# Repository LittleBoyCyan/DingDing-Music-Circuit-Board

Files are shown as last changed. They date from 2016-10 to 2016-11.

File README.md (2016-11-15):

# DingDing Music Circuit Board

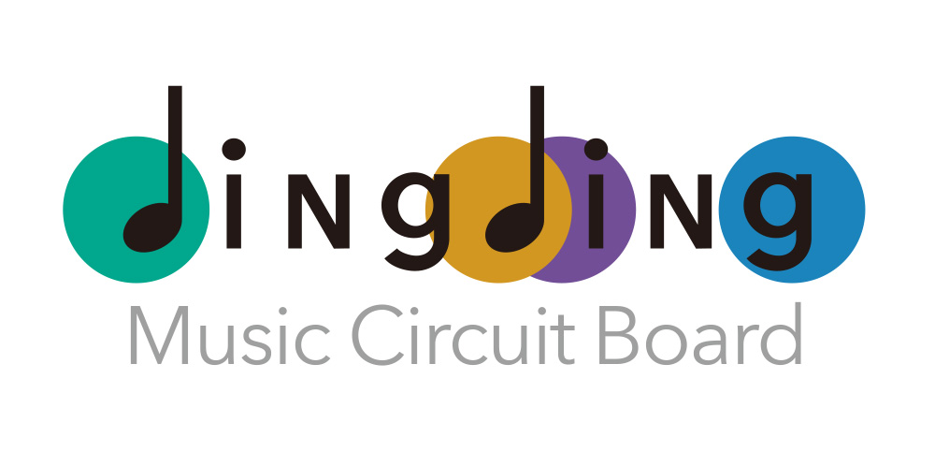
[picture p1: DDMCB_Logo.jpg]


<딩딩 뮤직 서킷 보드>는 리틀보이사이언에서 만든 아두이노 기반의 디지털 악기 보드 입니다. 

2016년 10월 서울, 세운상가에서 열린 메이커스 플랫폼 행사에서 세운상가의 마스터분들과의 협업으로 서울문화재단과 함께 제작하였습니다. 



<a href=http://bit.ly/dingdingmusiccircuitboard>악기 사용설명서 PDF 다운로드</a>

업데이트 중입니다 - - -

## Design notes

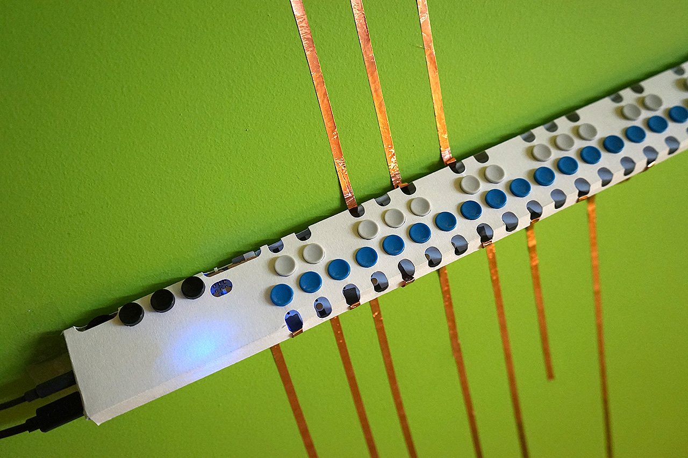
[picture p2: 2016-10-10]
DingDingMusicCircuitBoard.jpg

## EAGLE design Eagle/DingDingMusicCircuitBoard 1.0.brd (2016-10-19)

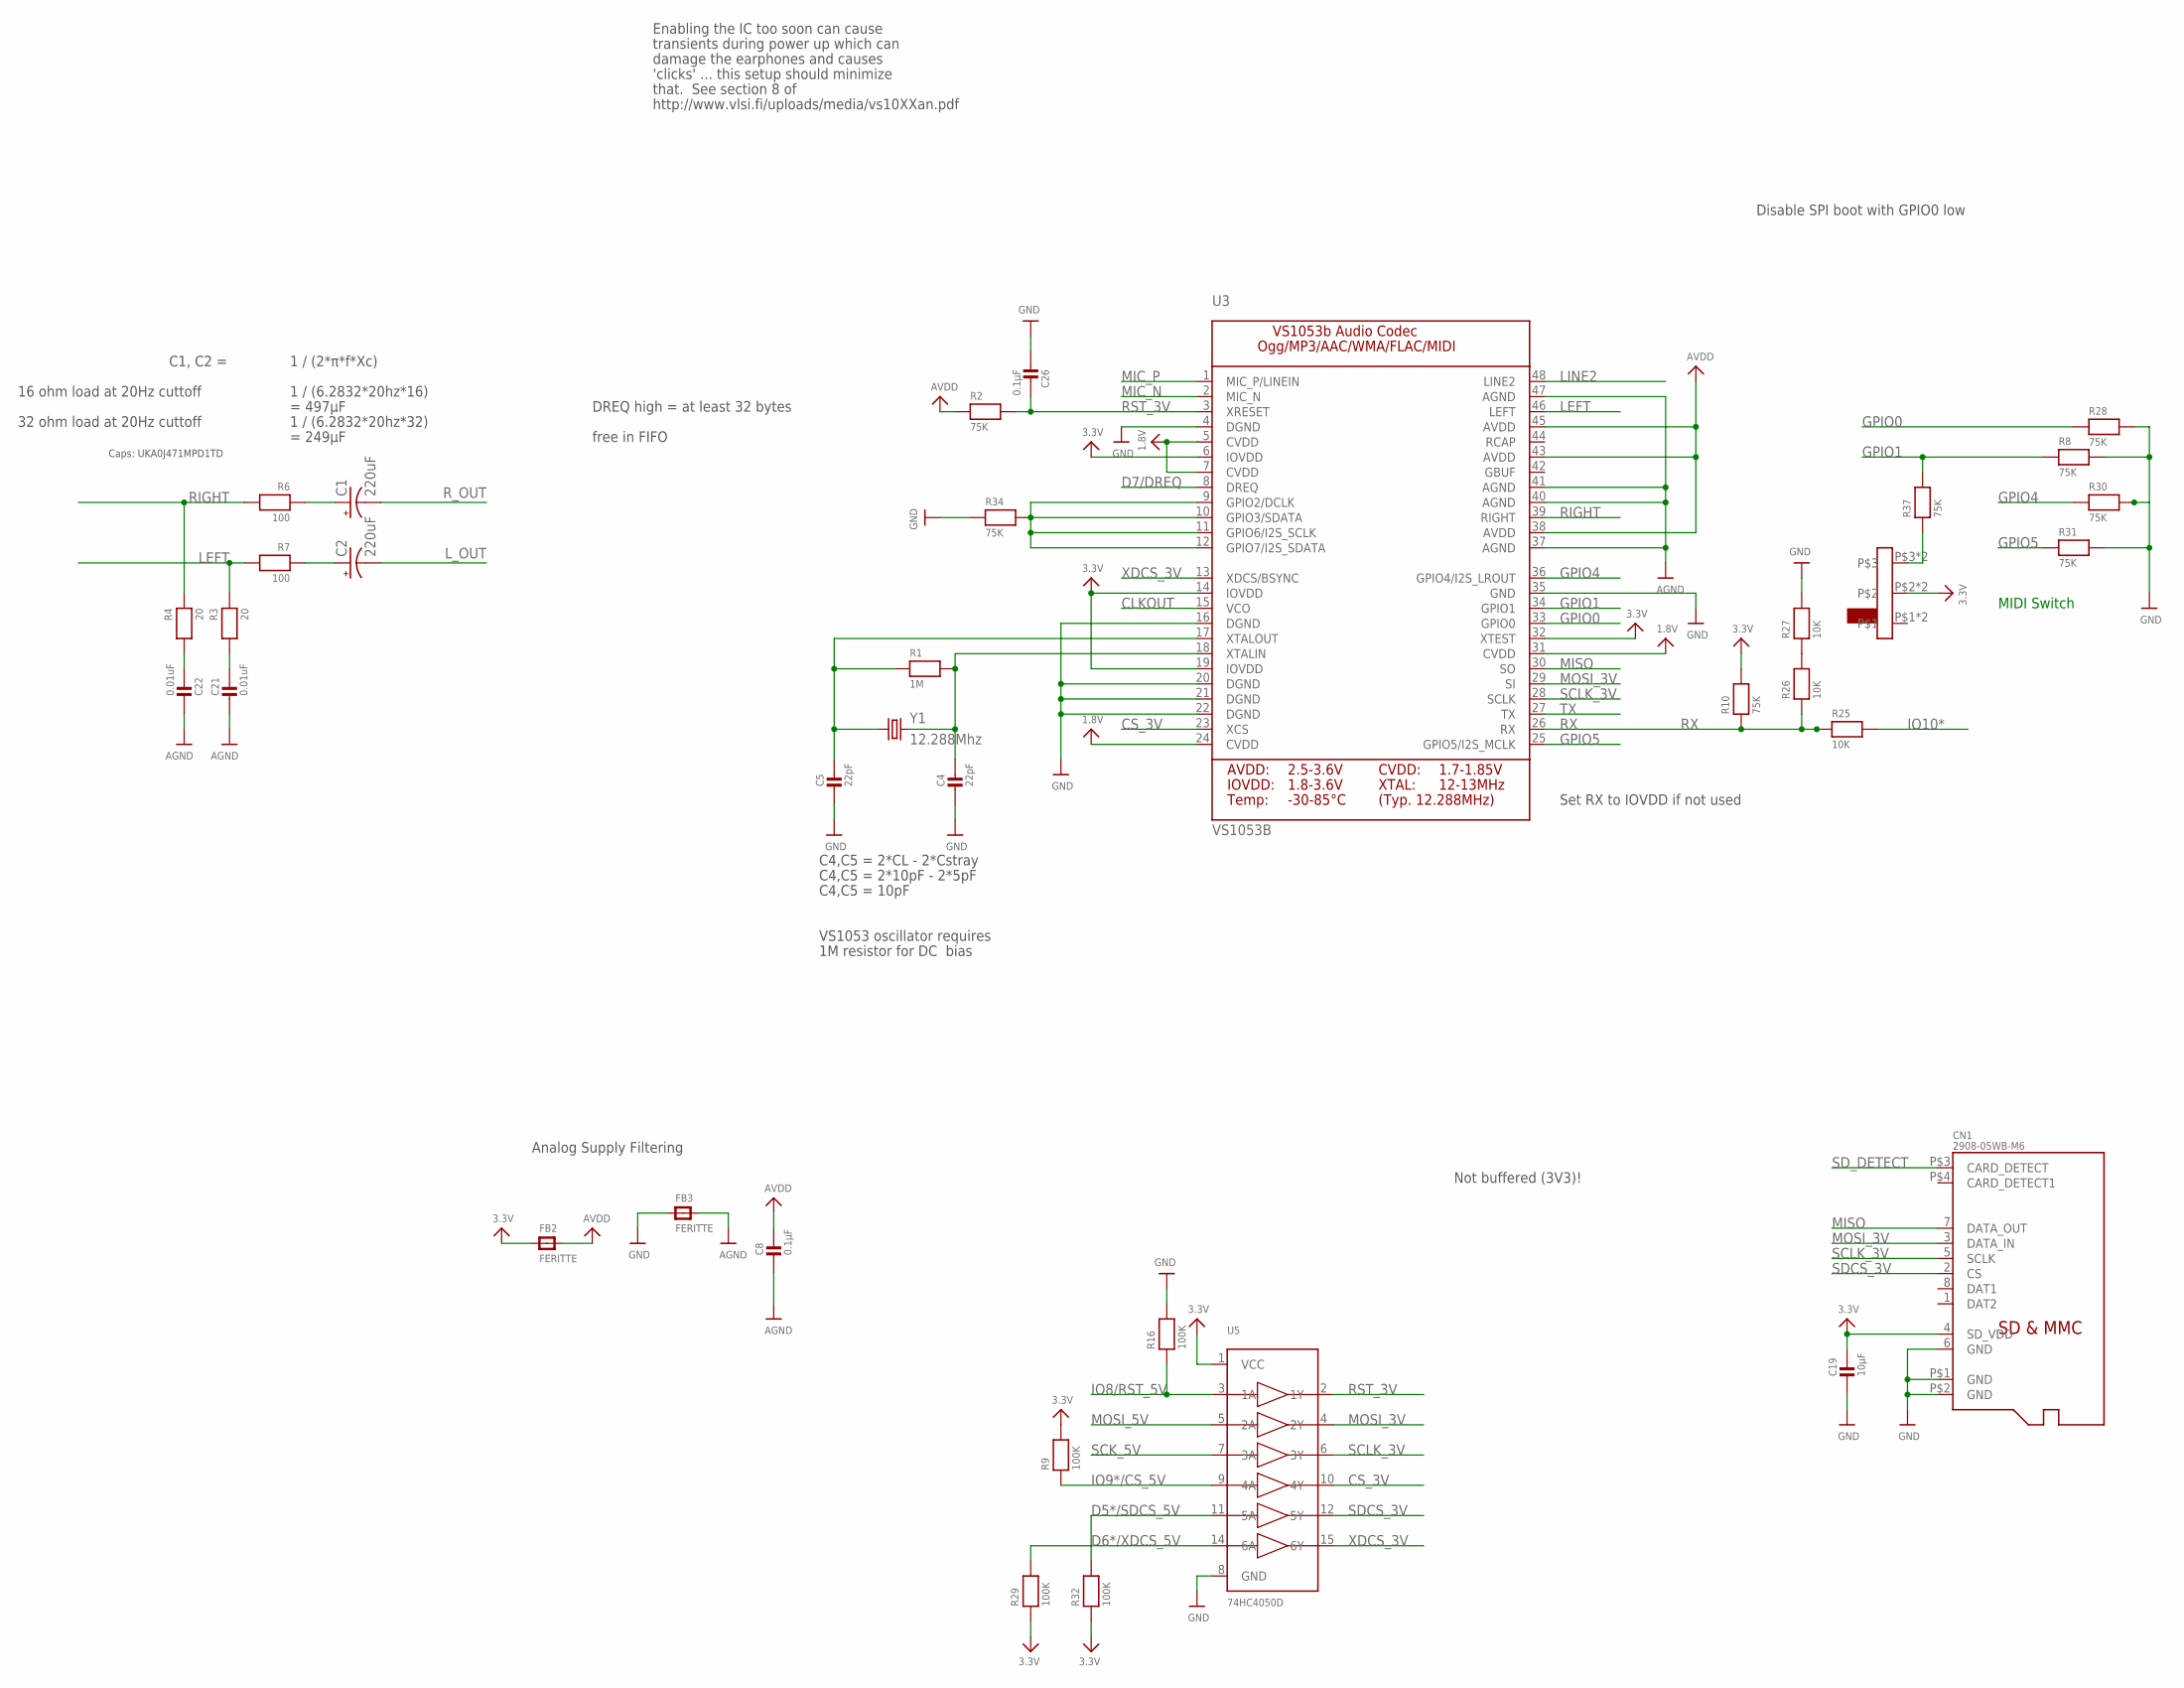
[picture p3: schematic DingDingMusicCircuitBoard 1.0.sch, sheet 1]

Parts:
C1, C2: 220uF; PANASONIC_D
C4, C5: 22pF; _0603MP
C8, C26: 0.1µF; _0603MP
C19: 10µF; _0603MP
C21, C22: 0.01uF; _0603MP
CN1: 2908-05WB-M6; MICROSD_MSDC-M61408
FB2, FB3: FERITTE; _0805MP
R1: 1M; _0603MP
R2, R8, R10, R28, R30, R31, R34, R37: 75K; _0603MP
R3, R4: 20; _0603MP
R6, R7: 100; _0603MP
R9, R16, R29, R32: 100K; _0603MP
R25, R26, R27: 10K; _0603MP
U3: VS1053B; LQFP48
U5: 74HC4050D; SOIC16
U$42: SWITCH_SK-02ACTS-2235S; SWITCH_CTS-2235S
Y1: 12.288Mhz; CRYSTAL-SMD-5X3

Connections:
1.8V: U3.5 (CVDD), U3.7 (CVDD), U3.24 (CVDD), U3.31 (CVDD); also elsewhere on the board
3.3V: C19.1, CN1.4 (SD_VDD), FB2.1, R9.2, R10.2, R29.1, R32.1, U3.6 (IOVDD), U3.14 (IOVDD), U3.19 (IOVDD), U3.32 (XTEST), U5.1 (VCC), U$42.P$2, U$42.P$5; also elsewhere on the board
AGND: C8.2, C21.2, C22.2, FB3.2, U3.37 (AGND), U3.40 (AGND), U3.41 (AGND), U3.47 (AGND); also elsewhere on the board
AVDD: C8.1, FB2.2, R2.1, U3.38 (AVDD), U3.43 (AVDD), U3.45 (AVDD)
CLKOUT: U3.15 (VCO)
CS_3V: U3.23 (XCS), U5.10 (4Y)
D5*/SDCS_5V: R32.2, U5.11 (5A); also elsewhere on the board
D6*/XDCS_5V: R29.2, U5.14 (6A); also elsewhere on the board
D7/DREQ: U3.8 (DREQ); also elsewhere on the board
GND: C4.2, C5.2, C19.2, C26.2, CN1.6 (GND), CN1.P$1 (GND), CN1.P$2 (GND), FB3.1, R8.2, R16.2, R27.2, R28.2, R30.2, R31.2, R34.1, U3.4 (DGND), U3.16 (DGND), U3.20 (DGND), U3.21 (DGND), U3.22 (DGND), U3.35 (GND), U5.8 (GND); also elsewhere on the board
GPIO0: R28.1, U3.33 (GPIO0)
GPIO1: R8.1, R37.2, U3.34 (GPIO1); also elsewhere on the board
GPIO3: R34.2, U3.9 (GPIO2/DCLK), U3.10 (GPIO3/SDATA), U3.11 (GPIO6/I2S_SCLK), U3.12 (GPIO7/I2S_SDATA)
GPIO4: R30.1, U3.36 (GPIO4/I2S_LROUT)
GPIO5: R31.1, U3.25 (GPIO5/I2S_MCLK)
IO8/RST_5V: R16.1, U5.3 (1A); also elsewhere on the board
IO9*/CS_5V: R9.1, U5.9 (4A); also elsewhere on the board
IO10*: R25.2; also elsewhere on the board
LEFT: R3.1, R7.2, U3.46 (LEFT)
LEFT_FILTERED: C2.+, R7.1
LINE2: U3.48 (LINE2)
L_OUT: C2.-; also elsewhere on the board
MIC_N: U3.2 (MIC_N)
MIC_P: U3.1 (MIC_P/LINEIN)
MISO: CN1.7 (DATA_OUT), U3.30 (SO); also elsewhere on the board
MOSI_3V: CN1.3 (DATA_IN), U3.29 (SI), U5.4 (2Y)
MOSI_5V: U5.5 (2A); also elsewhere on the board
unnamed: C5.1, R1.1, U3.17 (XTALOUT), Y1.1
unnamed: C4.1, R1.2, U3.18 (XTALIN), Y1.3 (2)
unnamed: C21.1, R3.2
unnamed: C22.1, R4.2
unnamed: R37.1, U$42.P$3, U$42.P$6
unnamed: R26.2, R27.1
RIGHT: R4.1, R6.2, U3.39 (RIGHT)
RIGHT_FILTERED: C1.+, R6.1
RST_3V: C26.1, R2.2, U3.3 (XRESET), U5.2 (1Y)
RX: R10.1, R25.1, R26.1, U3.26 (RX)
R_OUT: C1.-; also elsewhere on the board
SCK_5V: U5.7 (3A); also elsewhere on the board
SCLK_3V: CN1.5 (SCLK), U3.28 (SCLK), U5.6 (3Y)
SDCS_3V: CN1.2 (CS), U5.12 (5Y)
SD_DETECT: CN1.P$3 (CARD_DETECT)
TX: U3.27 (TX)
XDCS_3V: U3.13 (XDCS/BSYNC), U5.15 (6Y)

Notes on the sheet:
Analog Supply Filtering
C4,C5 = 2*CL - 2*Cstray
C4,C5 = 2*10pF - 2*5pF
C4,C5 = 10pF
VS1053 oscillator requires
1M resistor for DC bias
Set RX to IOVDD if not used
DREQ high = at least 32 bytes
Not buffered (3V3)!
transients during power up which can
damage the earphones and causes
'clicks' ... this setup should minimize
that. See section 8 of
http://www.vlsi.fi/uploads/media/vs10XXan.pdf
Enabling the IC too soon can cause
free in FIFO
Disable SPI boot with GPIO0 low
1 / (2*π*f*Xc)
16 ohm load at 20Hz cuttoff
1 / (6.2832*20hz*16)
C1, C2 =
= 497µF
32 ohm load at 20Hz cuttoff
1 / (6.2832*20hz*32)
= 249µF
Caps: UKA0J471MPD1TD
MIDI Switch

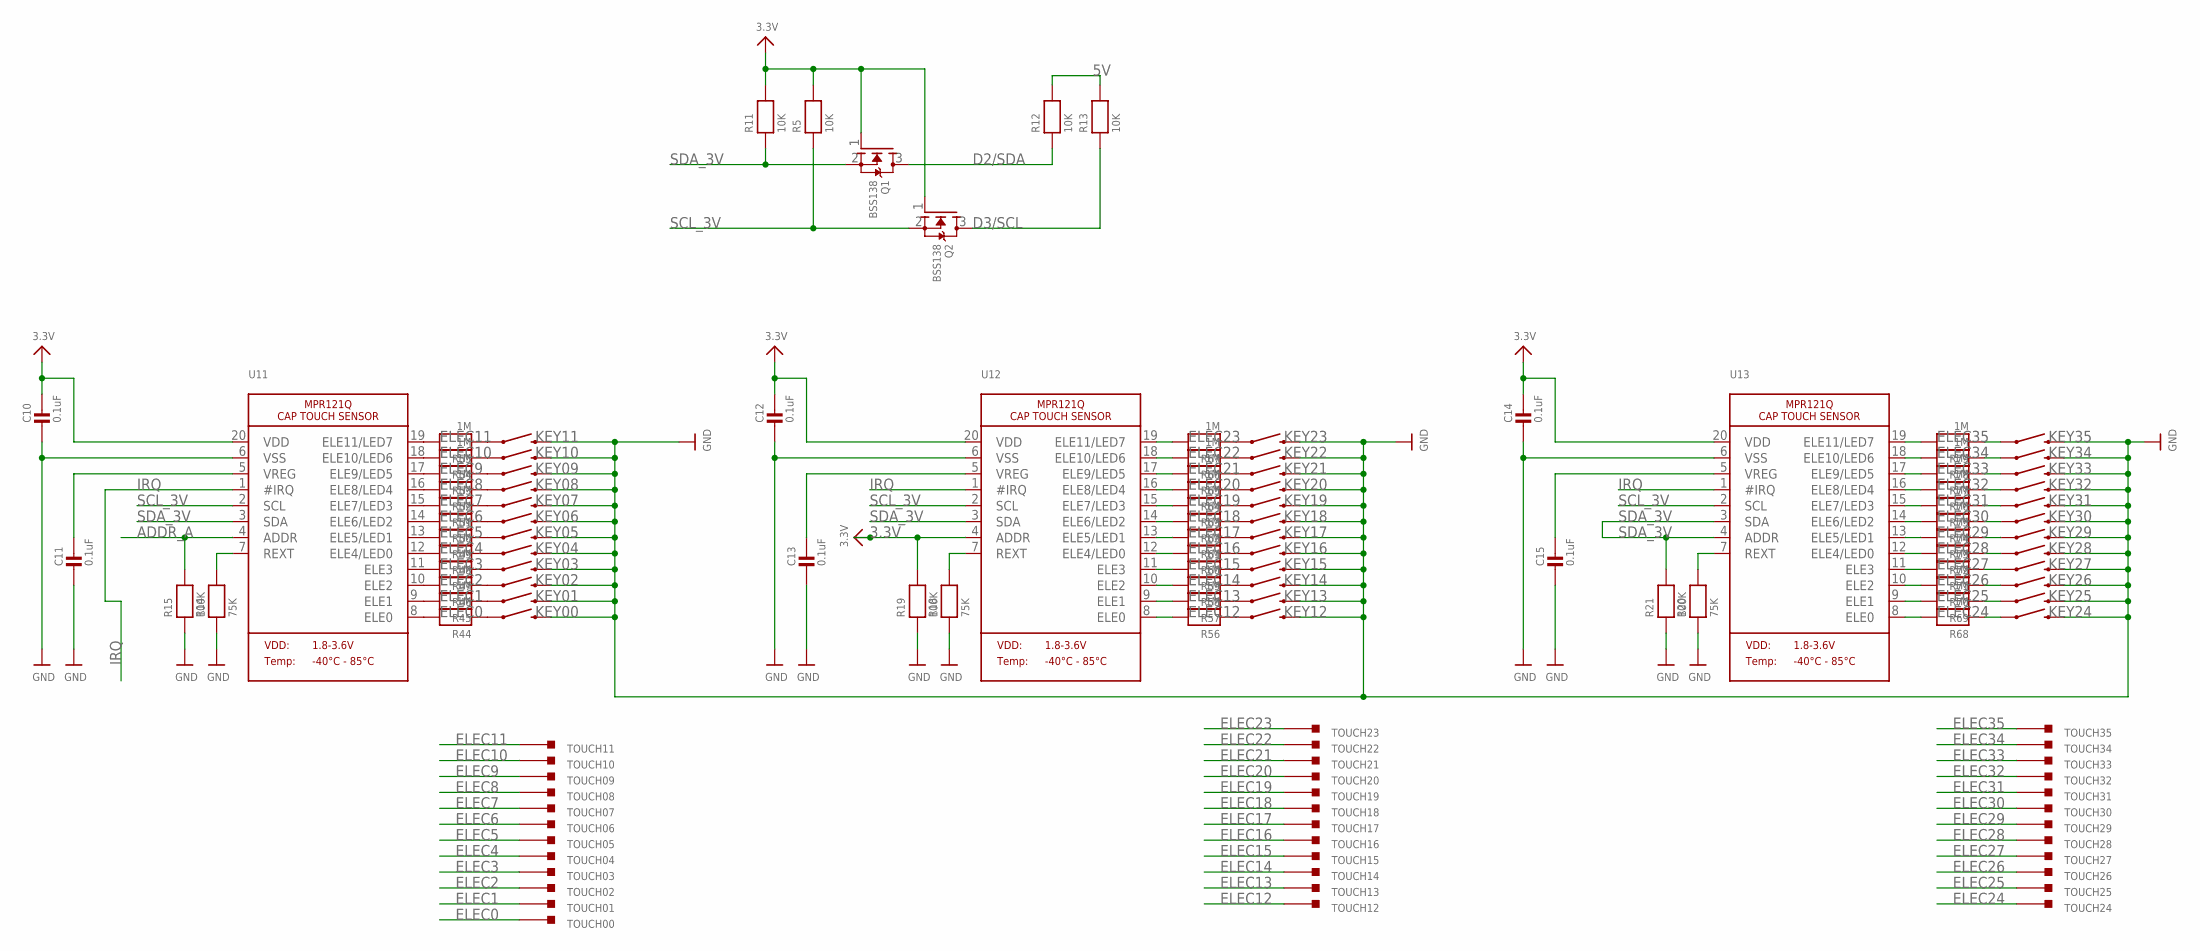
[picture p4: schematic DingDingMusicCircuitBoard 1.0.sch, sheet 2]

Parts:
C10, C11, C12, C13, C14, C15: 0.1uF; _0603MP
KEY00, KEY01, KEY02, KEY03, KEY04, KEY05, KEY06, KEY07, KEY08, KEY09, KEY10, KEY11, KEY12, KEY13, KEY14, KEY15, KEY16, KEY17, KEY18, KEY19, KEY20, KEY21, KEY22, KEY23, KEY24, KEY25, KEY26, KEY27, KEY28, KEY29, KEY30, KEY31, KEY32, KEY33, KEY34, KEY35: SWITCH-MOMENTARY-2; TACTILE_SWITCH_TALL
Q1, Q2: BSS138; SOT23-WIDE@1
R5, R11, R12, R13: 10K; _0603MP
R14, R18, R20: 75K; _0603MP
R15, R19, R21: 100K; _0603MP
R44, R45, R46, R47, R48, R49, R50, R51, R52, R53, R54, R55, R56, R57, R58, R59, R60, R61, R62, R63, R64, R65, R66, R67, R68, R69, R70, R71, R72, R73, R74, R75, R76, R77, R78, R79: 1M; _0603MP
TOUCH00, TOUCH01, TOUCH02, TOUCH03, TOUCH04, TOUCH05, TOUCH06, TOUCH07, TOUCH08, TOUCH09, TOUCH10, TOUCH11, TOUCH12, TOUCH13, TOUCH14, TOUCH15, TOUCH16, TOUCH17, TOUCH18, TOUCH19, TOUCH20, TOUCH21, TOUCH22, TOUCH23, TOUCH24, TOUCH25, TOUCH26, TOUCH27, TOUCH28, TOUCH29, TOUCH30, TOUCH31, TOUCH32, TOUCH33, TOUCH34, TOUCH35: RDD_TOUCH_PAD
U11, U12, U13: MPR121Q; QFN20_3MM_NOTHERMAL

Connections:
3.3V: C10.1, C12.1, C14.1, Q1.1 (G), Q2.1 (G), R5.2, R11.2, R19.2, U11.20 (VDD), U12.4 (ADDR), U12.20 (VDD), U13.20 (VDD); also elsewhere on the board
5V: R12.2, R13.2; also elsewhere on the board
ADDR_A: R15.2, U11.4 (ADDR)
D2/SDA: Q1.3 (D), R12.1; also elsewhere on the board
D3/SCL: Q2.3 (D), R13.1; also elsewhere on the board
ELEC0: R44.2, TOUCH00.P$1, U11.8 (ELE0)
ELEC1: R45.2, TOUCH01.P$1, U11.9 (ELE1)
ELEC2: R46.2, TOUCH02.P$1, U11.10 (ELE2)
ELEC3: R47.2, TOUCH03.P$1, U11.11 (ELE3)
ELEC4: R48.2, TOUCH04.P$1, U11.12 (ELE4/LED0)
ELEC5: R49.2, TOUCH05.P$1, U11.13 (ELE5/LED1)
ELEC6: R50.2, TOUCH06.P$1, U11.14 (ELE6/LED2)
ELEC7: R51.2, TOUCH07.P$1, U11.15 (ELE7/LED3)
ELEC8: R52.2, TOUCH08.P$1, U11.16 (ELE8/LED4)
ELEC9: R53.2, TOUCH09.P$1, U11.17 (ELE9/LED5)
ELEC10: R54.2, TOUCH10.P$1, U11.18 (ELE10/LED6)
ELEC11: R55.2, TOUCH11.P$1, U11.19 (ELE11/LED7)
ELEC12: R56.2, TOUCH12.P$1, U12.8 (ELE0)
ELEC13: R57.2, TOUCH13.P$1, U12.9 (ELE1)
ELEC14: R58.2, TOUCH14.P$1, U12.10 (ELE2)
ELEC15: R59.2, TOUCH15.P$1, U12.11 (ELE3)
ELEC16: R60.2, TOUCH16.P$1, U12.12 (ELE4/LED0)
ELEC17: R61.2, TOUCH17.P$1, U12.13 (ELE5/LED1)
ELEC18: R62.2, TOUCH18.P$1, U12.14 (ELE6/LED2)
ELEC19: R63.2, TOUCH19.P$1, U12.15 (ELE7/LED3)
ELEC20: R64.2, TOUCH20.P$1, U12.16 (ELE8/LED4)
ELEC21: R65.2, TOUCH21.P$1, U12.17 (ELE9/LED5)
ELEC22: R66.2, TOUCH22.P$1, U12.18 (ELE10/LED6)
ELEC23: R67.2, TOUCH23.P$1, U12.19 (ELE11/LED7)
ELEC24: R68.2, TOUCH24.P$1, U13.8 (ELE0)
ELEC25: R69.2, TOUCH25.P$1, U13.9 (ELE1)
ELEC26: R70.2, TOUCH26.P$1, U13.10 (ELE2)
ELEC27: R71.2, TOUCH27.P$1, U13.11 (ELE3)
ELEC28: R72.2, TOUCH28.P$1, U13.12 (ELE4/LED0)
ELEC29: R73.2, TOUCH29.P$1, U13.13 (ELE5/LED1)
ELEC30: R74.2, TOUCH30.P$1, U13.14 (ELE6/LED2)
ELEC31: R75.2, TOUCH31.P$1, U13.15 (ELE7/LED3)
ELEC32: R76.2, TOUCH32.P$1, U13.16 (ELE8/LED4)
ELEC33: R77.2, TOUCH33.P$1, U13.17 (ELE9/LED5)
ELEC34: R78.2, TOUCH34.P$1, U13.18 (ELE10/LED6)
ELEC35: R79.2, TOUCH35.P$1, U13.19 (ELE11/LED7)
GND: C10.2, C11.2, C12.2, C13.2, C14.2, C15.2, KEY00.B1 (2), KEY00.B2 (2), KEY01.B1 (2), KEY01.B2 (2), KEY02.B1 (2), KEY02.B2 (2), KEY03.B1 (2), KEY03.B2 (2), KEY04.B1 (2), KEY04.B2 (2), KEY05.B1 (2), KEY05.B2 (2), KEY06.B1 (2), KEY06.B2 (2), KEY07.B1 (2), KEY07.B2 (2), KEY08.B1 (2), KEY08.B2 (2), KEY09.B1 (2), KEY09.B2 (2), KEY10.B1 (2), KEY10.B2 (2), KEY11.B1 (2), KEY11.B2 (2), KEY12.B1 (2), KEY12.B2 (2), KEY13.B1 (2), KEY13.B2 (2), KEY14.B1 (2), KEY14.B2 (2), KEY15.B1 (2), KEY15.B2 (2), KEY16.B1 (2), KEY16.B2 (2), KEY17.B1 (2), KEY17.B2 (2), KEY18.B1 (2), KEY18.B2 (2), KEY19.B1 (2), KEY19.B2 (2), KEY20.B1 (2), KEY20.B2 (2), KEY21.B1 (2), KEY21.B2 (2), KEY22.B1 (2), KEY22.B2 (2), KEY23.B1 (2), KEY23.B2 (2), KEY24.B1 (2), KEY24.B2 (2), KEY25.B1 (2), KEY25.B2 (2), KEY26.B1 (2), KEY26.B2 (2), KEY27.B1 (2), KEY27.B2 (2), KEY28.B1 (2), KEY28.B2 (2), KEY29.B1 (2), KEY29.B2 (2), KEY30.B1 (2), KEY30.B2 (2), KEY31.B1 (2), KEY31.B2 (2), KEY32.B1 (2), KEY32.B2 (2), KEY33.B1 (2), KEY33.B2 (2), KEY34.B1 (2), KEY34.B2 (2), KEY35.B1 (2), KEY35.B2 (2), R14.1, R15.1, R18.1, R19.1, R20.1, R21.1, U11.6 (VSS), U12.6 (VSS), U13.6 (VSS); also elsewhere on the board
IRQ: U11.1 (#IRQ), U12.1 (#IRQ), U13.1 (#IRQ); also elsewhere on the board
unnamed: C11.1, U11.5 (VREG)
unnamed: R14.2, U11.7 (REXT)
unnamed: C13.1, U12.5 (VREG)
unnamed: R18.2, U12.7 (REXT)
unnamed: C15.1, U13.5 (VREG)
unnamed: R20.2, U13.7 (REXT)
unnamed: KEY00.A1 (1), KEY00.A2 (1), R44.1
unnamed: KEY01.A1 (1), KEY01.A2 (1), R45.1
unnamed: KEY02.A1 (1), KEY02.A2 (1), R46.1
unnamed: KEY03.A1 (1), KEY03.A2 (1), R47.1
unnamed: KEY04.A1 (1), KEY04.A2 (1), R48.1
unnamed: KEY05.A1 (1), KEY05.A2 (1), R49.1
unnamed: KEY06.A1 (1), KEY06.A2 (1), R50.1
unnamed: KEY07.A1 (1), KEY07.A2 (1), R51.1
unnamed: KEY08.A1 (1), KEY08.A2 (1), R52.1
unnamed: KEY09.A1 (1), KEY09.A2 (1), R53.1
unnamed: KEY10.A1 (1), KEY10.A2 (1), R54.1
unnamed: KEY11.A1 (1), KEY11.A2 (1), R55.1
unnamed: KEY12.A1 (1), KEY12.A2 (1), R56.1
unnamed: KEY13.A1 (1), KEY13.A2 (1), R57.1
unnamed: KEY14.A1 (1), KEY14.A2 (1), R58.1
unnamed: KEY15.A1 (1), KEY15.A2 (1), R59.1
unnamed: KEY16.A1 (1), KEY16.A2 (1), R60.1
unnamed: KEY17.A1 (1), KEY17.A2 (1), R61.1
unnamed: KEY18.A1 (1), KEY18.A2 (1), R62.1
unnamed: KEY19.A1 (1), KEY19.A2 (1), R63.1
unnamed: KEY20.A1 (1), KEY20.A2 (1), R64.1
unnamed: KEY21.A1 (1), KEY21.A2 (1), R65.1
unnamed: KEY22.A1 (1), KEY22.A2 (1), R66.1
unnamed: KEY23.A1 (1), KEY23.A2 (1), R67.1
unnamed: KEY24.A1 (1), KEY24.A2 (1), R68.1
unnamed: KEY25.A1 (1), KEY25.A2 (1), R69.1
unnamed: KEY26.A1 (1), KEY26.A2 (1), R70.1
unnamed: KEY27.A1 (1), KEY27.A2 (1), R71.1
unnamed: KEY28.A1 (1), KEY28.A2 (1), R72.1
unnamed: KEY29.A1 (1), KEY29.A2 (1), R73.1
unnamed: KEY30.A1 (1), KEY30.A2 (1), R74.1
unnamed: KEY31.A1 (1), KEY31.A2 (1), R75.1
unnamed: KEY32.A1 (1), KEY32.A2 (1), R76.1
unnamed: KEY33.A1 (1), KEY33.A2 (1), R77.1
unnamed: KEY34.A1 (1), KEY34.A2 (1), R78.1
unnamed: KEY35.A1 (1), KEY35.A2 (1), R79.1
SCL_3V: Q2.2 (S), R5.1, U11.2 (SCL), U12.2 (SCL), U13.2 (SCL)
SDA_3V: Q1.2 (S), R11.1, R21.2, U11.3 (SDA), U12.3 (SDA), U13.3 (SDA), U13.4 (ADDR)

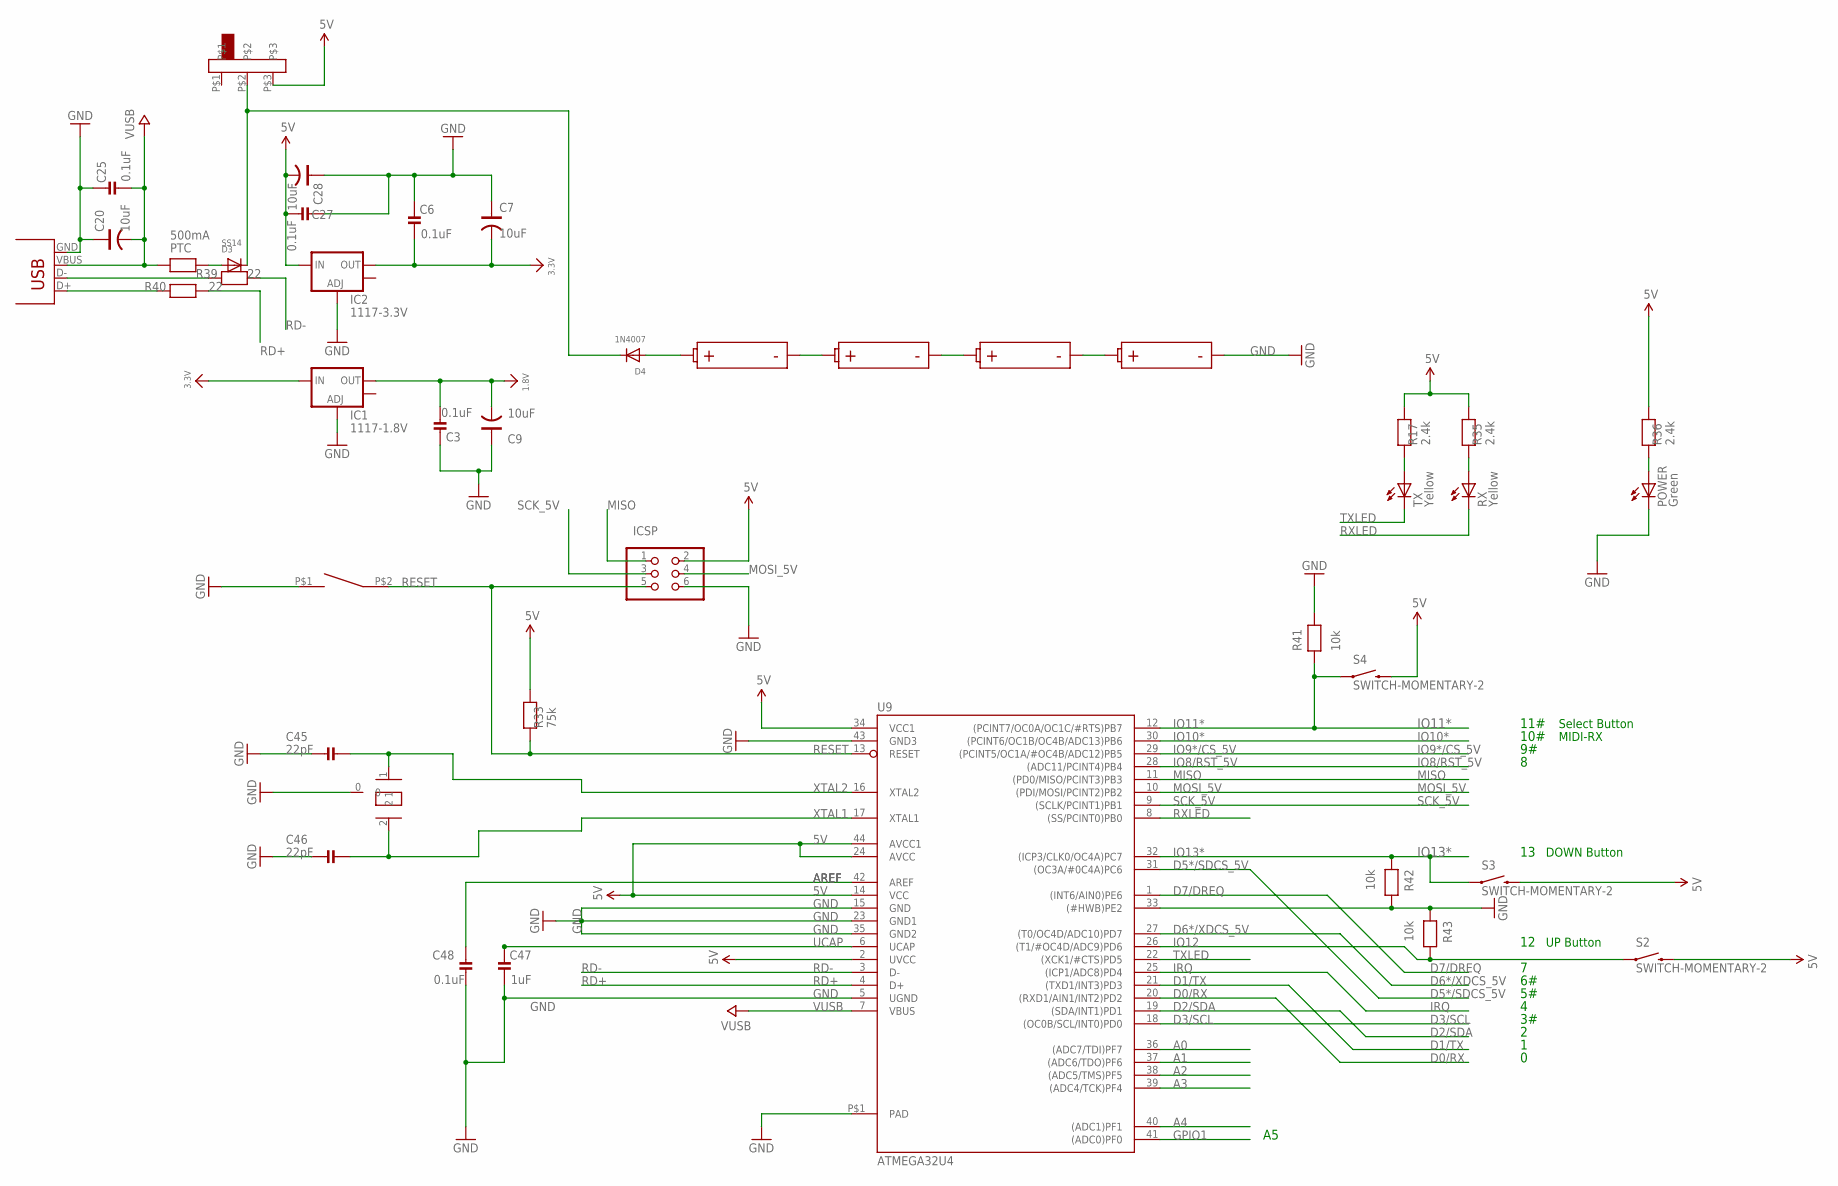
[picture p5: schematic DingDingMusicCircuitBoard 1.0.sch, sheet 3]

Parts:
AAA01, AAA02, AAA03, AAA04: AAA_CLIP
C3, C6, C25, C27: 0.1uF; _0805MP
C7, C9, C20, C28: 10uF; 1206
C45, C46: 22pF; _0603MP
C47: 1uF; _0603MP
C48: 0.1uF; _0603MP
D3: SS14; SOD-123
D4: 1N4007; SOD-123
IC1: 1117-1.8V; SOT223
IC2: 1117-3.3V; SOT223
ICSP: ICSP; 2X03
POWER: Green; CHIPLED_0805
PTC: 500mA; _0805MP
R17, R35, R36: 2.4k; _0603MP
R33: 75k; _0603MP
R39, R40: 22; _0603MP
R41, R42, R43: 10k; _0603MP
RESET: TACT_SWITCHSMALL; TACT_SWITCH_SMALL
RX: Yellow; CHIPLED_0805
S2, S3, S4: SWITCH-MOMENTARY-2; TACTILE_SWITCH_TALL
TX: Yellow; CHIPLED_0805
U9: ATMEGA32U4; TQFP44-PAD
U$44: SWITCH_SK-02ACTS-1280; SWITCH_CTS-1280
U$47: MURATA_CRYSTAL
U$70: MICRO_USB

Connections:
1.8V: C3.1, C9.2, IC1.2 (OUT); also elsewhere on the board
3.3V: C6.1, C7.2, IC1.3 (IN), IC2.2 (OUT); also elsewhere on the board
5V: C27.1, C28.2, IC2.3 (IN), ICSP.2, R17.1, R33.1, R35.1, R36.1, S2.B1 (2), S2.B2 (2), S3.B1 (2), S3.B2 (2), S4.B1 (2), S4.B2 (2), U9.2 (UVCC), U9.14 (VCC), U9.24 (AVCC), U9.34 (VCC1), U9.44 (AVCC1), U$44.P$3; also elsewhere on the board
A0: U9.36 ((ADC7/TDI)PF7)
A1: U9.37 ((ADC6/TDO)PF6)
A2: U9.38 ((ADC5/TMS)PF5)
A3: U9.39 ((ADC4/TCK)PF4)
A4: U9.40 ((ADC1)PF1)
AREF: C48.2, U9.42 (AREF)
D0/RX: U9.20 ((RXD1/AIN1/INT2)PD2)
D1/TX: U9.21 ((TXD1/INT3)PD3)
D2/SDA: U9.19 ((SDA/INT1)PD1); also elsewhere on the board
D3/SCL: U9.18 ((OC0B/SCL/INT0)PD0); also elsewhere on the board
D5*/SDCS_5V: U9.31 ((OC3A/#0C4A)PC6); also elsewhere on the board
D6*/XDCS_5V: U9.27 ((T0/OC4D/ADC10)PD7); also elsewhere on the board
D7/DREQ: U9.1 ((INT6/AIN0)PE6); also elsewhere on the board
GND: AAA04.P$3- (P$2-), AAA04.P$4- (P$2-), C3.2, C6.2, C7.1, C9.1, C20.1, C25.2, C27.2, C28.1, C45.2, C46.2, C47.1, C48.1, IC1.1 (ADJ), IC2.1 (ADJ), ICSP.6, POWER.C, R41.1, R42.1, R43.2, RESET.P$1, U9.5 (UGND), U9.15 (GND), U9.23 (GND1), U9.33 ((#HWB)PE2), U9.35 (GND2), U9.43 (GND3), U9.P$1 (PAD), U$47.0, U$70.GND; also elsewhere on the board
GPIO1: U9.41 ((ADC0)PF0); also elsewhere on the board
IO8/RST_5V: U9.28 ((ADC11/PCINT4)PB4); also elsewhere on the board
IO9*/CS_5V: U9.29 ((PCINT5/OC1A/#OC4B/ADC12)PB5); also elsewhere on the board
IO10*: U9.30 ((PCINT6/OC1B/OC4B/ADC13)PB6); also elsewhere on the board
IO11*: R41.2, S4.A1 (1), S4.A2 (1), U9.12 ((PCINT7/OC0A/OC1C/#RTS)PB7)
IO12: R43.1, S2.A1 (1), S2.A2 (1), U9.26 ((T1/#OC4D/ADC9)PD6)
IO13*: R42.2, S3.A1 (1), S3.A2 (1), U9.32 ((ICP3/CLK0/OC4A)PC7)
IRQ: U9.25 ((ICP1/ADC8)PD4); also elsewhere on the board
MISO: ICSP.1, U9.11 ((PD0/MISO/PCINT3)PB3); also elsewhere on the board
MOSI_5V: ICSP.4, U9.10 ((PDI/MOSI/PCINT2)PB2); also elsewhere on the board
unnamed: POWER.A, R36.2
unnamed: D3.A, PTC.1
unnamed: AAA01.P$3- (P$2-), AAA01.P$4- (P$2-), AAA02.P$1+, AAA02.P$2+ (P$1+)
unnamed: AAA02.P$3- (P$2-), AAA02.P$4- (P$2-), AAA03.P$1+, AAA03.P$2+ (P$1+)
unnamed: R17.2, TX.A
unnamed: R35.2, RX.A
unnamed: AAA01.P$1+, AAA01.P$2+ (P$1+), D4.A
unnamed: AAA03.P$3- (P$2-), AAA03.P$4- (P$2-), AAA04.P$1+, AAA04.P$2+ (P$1+)
unnamed: R39.2, U$70.D-
unnamed: R40.2, U$70.D+
unnamed: D3.C, D4.C, U$44.P$2
RD+: R40.1, U9.4 (D+)
RD-: R39.1, U9.3 (D-)
RESET: ICSP.5, R33.2, RESET.P$2, U9.13 (RESET)
RXLED: RX.C, U9.8 ((SS/PCINT0)PB0)
SCK_5V: ICSP.3, U9.9 ((SCLK/PCINT1)PB1); also elsewhere on the board
TXLED: TX.C, U9.22 ((XCK1/#CTS)PD5)
UCAP: C47.2, U9.6 (UCAP)
VUSB: C20.2, C25.1, PTC.2, U9.7 (VBUS), U$70.VBUS
XTAL1: C46.1, U9.17 (XTAL1), U$47.2
XTAL2: C45.1, U9.16 (XTAL2), U$47.1

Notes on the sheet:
10#
11#
MIDI-RX
Select Button
DOWN Button
UP Button

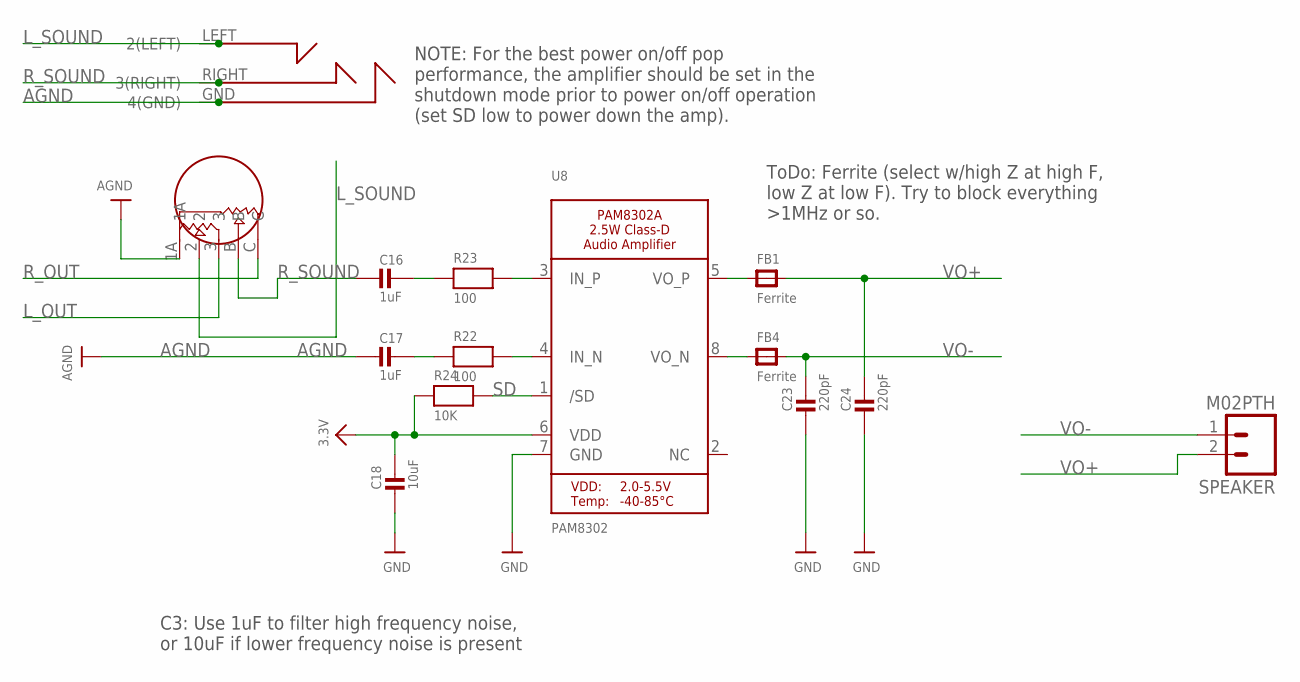
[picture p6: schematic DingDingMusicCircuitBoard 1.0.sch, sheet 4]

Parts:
C16, C17: 1uF; _0603MP
C18: 10uF; _0603MP
C23, C24: 220pF; _0603MP
FB1, FB4: Ferrite; _0805MP
R22, R23: 100; _0603MP
R24: 10K; _0603MP
SPEAKER: M02PTH; 1X02
U8: PAM8302; MSOP8_0.65MM
U$32: SOUND_VOLUME
U$80: EARPHONE_DEV; EARPHONE_PAC

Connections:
3.3V: C18.1, R24.1, U8.6 (VDD); also elsewhere on the board
AGND: C17.2, U$32.1A, U$80.GND (4(GND)); also elsewhere on the board
GND: C18.2, C23.2, C24.2, U8.7 (GND); also elsewhere on the board
L_OUT: U$32.3; also elsewhere on the board
L_SOUND: U$32.2, U$80.LEFT (2(LEFT))
unnamed: R22.2, U8.4 (IN_N)
unnamed: R23.2, U8.3 (IN_P)
unnamed: C17.1, R22.1
unnamed: FB4.1, U8.8 (VO_N)
unnamed: FB1.1, U8.5 (VO_P)
unnamed: C16.1, R23.1
R_OUT: U$32.C; also elsewhere on the board
R_SOUND: C16.2, U$32.B, U$80.RIGHT (3(RIGHT))
SD: R24.2, U8.1 (/SD)
VO+: C24.1, FB1.2, SPEAKER.2
VO-: C23.1, FB4.2, SPEAKER.1

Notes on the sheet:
ToDo: Ferrite (select w/high Z at high F, low Z at low F). Try to block everything >1MHz or so.
C3: Use 1uF to filter high frequency noise, or 10uF if lower frequency noise is present
NOTE: For the best power on/off pop performance, the amplifier should be set in the shutdown mode prior to power on/off operation (set SD low to power down the amp).

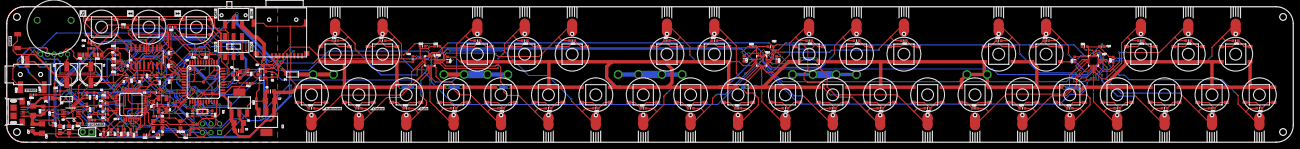
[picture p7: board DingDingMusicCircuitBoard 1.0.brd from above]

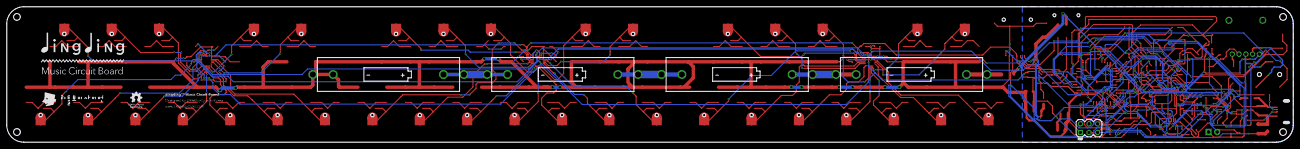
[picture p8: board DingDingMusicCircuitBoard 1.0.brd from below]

Board: 2 copper layers, 380.0 x 40.0 mm, 272 parts (3 on the bottom side), 158 nets.

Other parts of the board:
U$41: DD_SILK_FUNTION
U$61: DD_SILK_BACK
U$62: DD_SILK_FORWARD
U$63: DD_SILK_RESET
U$81: DD_SILK_STEREO
U$82: DD_SILK_ON
U$83: DD_SILK_OFF
U$84: DD_SILK_MIDI
U$85: DD_SILK_MP3
U$86: DD_SILK_INST
U$87: DD_SILK_OCTAVE
U$88: DD_SILK_SCALE
U$89: DD_SILK_SPEAKER
U$90, U$91, U$92, U$93, U$94, U$95, U$96, U$97, U$98, U$99, U$100, U$101, U$102, U$103, U$104, U$105, U$106, U$107, U$108, U$109, U$110, U$111, U$112, U$113, U$114, U$115, U$116, U$117, U$118, U$119, U$120, U$121, U$122, U$123, U$124, U$125: DD_SILK_FINGER_LINE
U$126: DD_SILK_LOGO01
U$127: DD_SILK_LOGO02

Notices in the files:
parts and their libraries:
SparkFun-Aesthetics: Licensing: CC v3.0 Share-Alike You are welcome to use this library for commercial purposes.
